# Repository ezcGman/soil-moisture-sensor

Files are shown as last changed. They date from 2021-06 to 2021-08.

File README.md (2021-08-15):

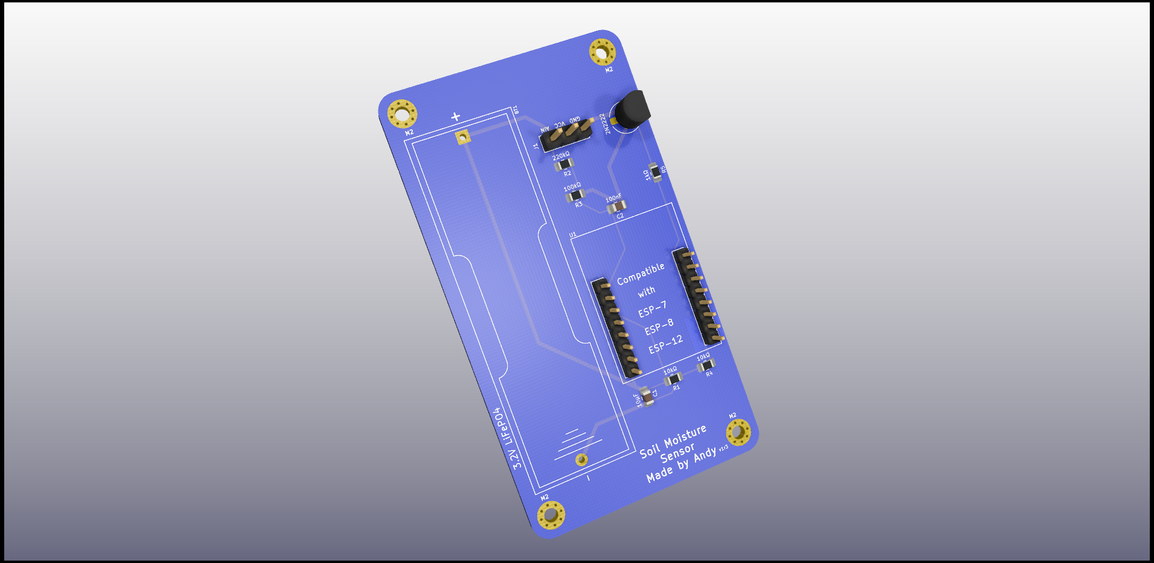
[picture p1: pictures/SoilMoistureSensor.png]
The PCB


# Soil Moisture Sensor
This is one of my first self designed PCBs in KiCad. It's a simple circuit which makes use of an ESP8266 and a soil moisture sensor to observe your plants. The cool thing: My custom socket supports the ESP-12E/F, the ESP-8 and the cool ESP-7, which comes with an external antennna!

## Credits
Shoutout to Quindor from QuinLED.info, the LED master himself. He tought me a lot about KiCad, PCB design and some more electrical engineering fundamentals! While I'm still miles away from being perfect, with his help I really feel confident in what I'm doing here!

## KiCad dependencies
It might happen that KiCad is missing my custom footprints. You can find and download them here and then add them to KiCad: https://github.com/ezcGman/andys-footprints

## Parts list
All these parts can be easily found on AliExpress (except the PCBs ;) ):

- 1x The PCB in this folder, printed e.g. at PCBWay
- 1x 3.2V LiFePO4 battery in AA form factor
- 1x AA battery holder for THT mounting
- 1x capactive soil moisture sensor (some notes on capacitive vs. resistive sensors can be found a bit further down)
- 1x bare ESP8266 module, so no devboard like the famous NodeMCU or D1 Mini. The socket supports the ESP-12E/F, ESP-8 and ESP-7. But in the end, there are only two choices:
  - ESP-12E/F: If you don't need an external antenna / your Wi-Fi signal is good, get this one. It's super common, easy to get and cheap.
  - ESP-7: If you do need an external antenna, get this one. Often also comes directly with an antenna! 
- 1x NPN transistor. Probably most transistors are fine, but I suggest the 2n2222(a) which is super common and totally sufficient for this
- 1x 0805 SMD capacitor of 10µF or bigger. But 0805 SMD caps are usually limited to ~40µF. So whatever u have around
- 1x 0805 SMD capacitor of 100nF
- 1x 0805 resistor of 1kΩ
- 2x 0805 resistor of 10kΩ
- 1x 0805 resistor of 100kΩ
- 1x 0805 resistor of 220kΩ
- 2x **2mm** (**not** 2.54mm!!) single row pin headers of 8 pins each
- 1x 2.54mm single row pin header of 3 pins

## Tools list
### Required
- A soldering iron
- Soldering tin

### Optional
- For SMD components:
  - A hot air soldering/reflow station. However, those are 0805 SMD components which can be done with a soldering iron
  - Solder paste
  - Tweezers

## The code
If you're familiar with ESP coding, this should all be straight forward, but some key things in there:
* The whole code is in setup() as the ESP goes through it when doing timed deep sleep using the GPIO16-to-RST method. Because the "wake up" is actually a reset, because the RST is pulled low.
* I'm using the sensor in Home Assistant through MQTT, so the code has some MQTT logic
* Both my Wi-Fi and MQTT connect routines have some reconnect logic.
* GPIO4 is used to switch on the sensor, so this is one of the very first things the code does. This is done by pulling it HIGH, which will switch the transistor which then makes the full circuit of the sensor complete, by letting the electrones flow from GND to the sensor.
* I then just read from the A0 pin, convert it in C-super-complicated-style (Python developer speaking here!) to a char and dropping it into an MQTT topic.
* It also has some percentage calculation, which is based on my own measurements of the sensor. These are the "air value" (so sensor just laying around) and the "water value" (which is the sensor put into a glas of clear water).
* Another thing is a "dry/wet threshold", which is based on my girlfriend: She said "Andy, this is now dry!". And I took this as the threshold (minus a little bit for earlier alerts) for considering a plant being dry. Note, that this may vary by plant and flower soil used.
* Ultimately not needed, but for easier checking if the battery is empty (=no signal is sent anymore): A "last updated" timestamp also dropped into the MQTT topic

### Dependencies
* Arduino Client for MQTT, >=v2.8.0: https://pubsubclient.knolleary.net/
* Optional (can use built-in DateTime): ESPDateTime, >=v1.0.4: https://github.com/mcxiaoke/ESPDateTime

## Schematic
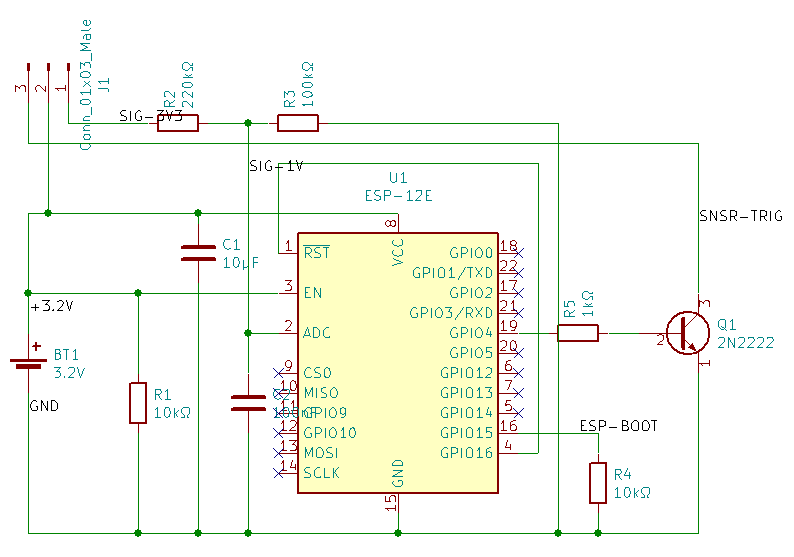
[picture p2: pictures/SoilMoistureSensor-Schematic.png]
The Schematic


## Why a bare ESP-12F, why not using a devboard like D1 or NodeMCU?
Easy answer: Power consumption + deep sleep. All these dev boards have an USB UART that is **always on**, even in deep sleep. And this eats a lot of energy. There is a really good post about why you should use ESP-12F over these devboards: https://github.com/z2amiller/sensorboard/blob/master/PowerSaving.md
Also: There is a reason why they are called **dev**boards ;) They are not really meant to be used "in production."

## Which kind of soil moisture sensors exist / should I use?
### 1. Electrical conduction sensors (Don't use: Boooo!)
When I was first playing with these soil moisture sensors, I've started with these sensors, which have a (visible) copper/some metal layer and two legs: They measure the soil moisture based on the electrical conduction of the soil / between the two legs.
The downside of these is that they can corrode and actually harm the plants, instead of surveiling them ;) And I don't know what upsides they actually have compared to:

### 2. Capacitive Soil Moisture Sensor (Use: Coooool!)
You guessed it: These sensors work by measuring the capacitance of the sensor (or it's layers (the electrodes)), where the soil and water function as the dielectric. These do not have copper layers being exposed which could corrode, so make them safe to use in any plant.
If you **really** want to deep dive into how these sensors work and how to properly calibrate them, lead this publication: https://www.researchgate.net/publication/342751186_Capacitive_Soil_Moisture_Sensor_Theory_Calibration_and_Testing

## How it looks
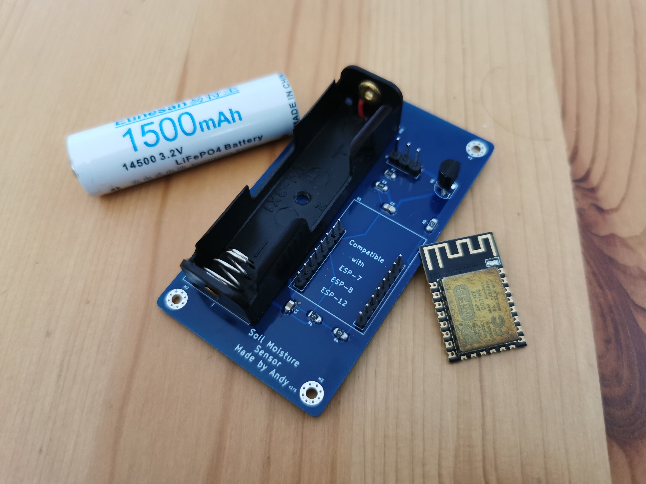
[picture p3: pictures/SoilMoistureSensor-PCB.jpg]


## Example application with an ESP-07 / external antenna outside (waterproof)
*Yes, I know: This is currently an ESP-12F, because I'm waiting for the ESP-07 to arrive. But then this will be powered by an ESP-07 ;)*
I just used an old jelly glass, drilled two holes in it and sealed them with hot glue. Therefore it's perfectly waterproof :)
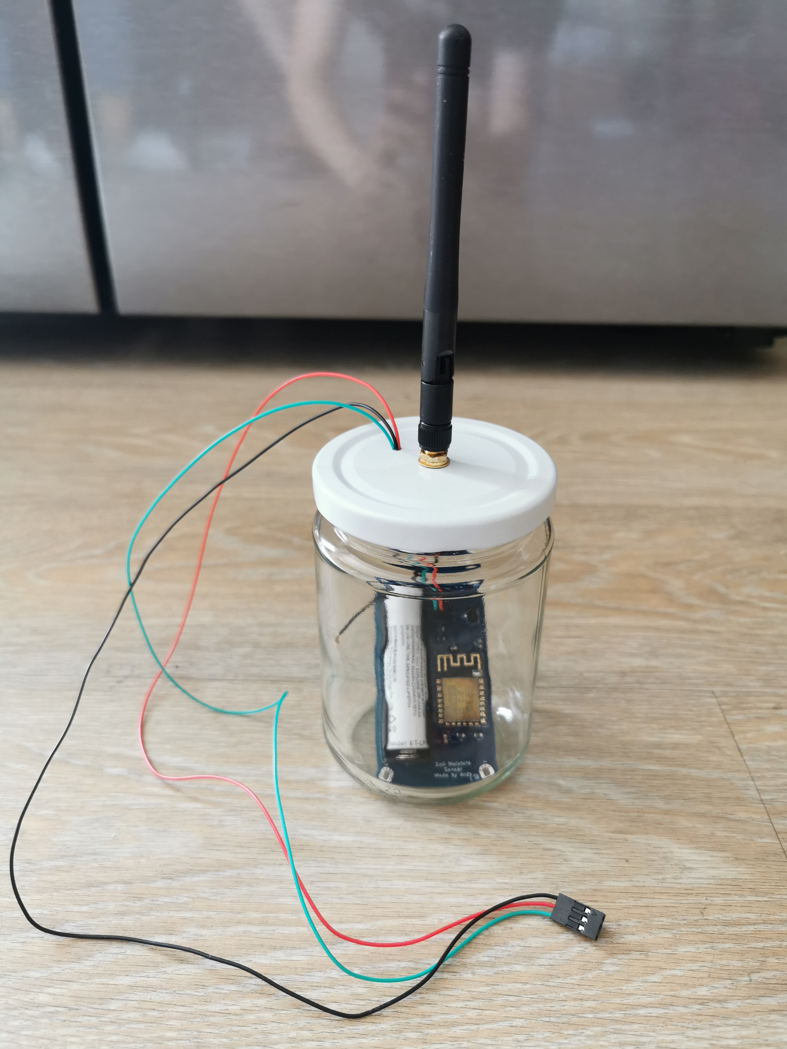
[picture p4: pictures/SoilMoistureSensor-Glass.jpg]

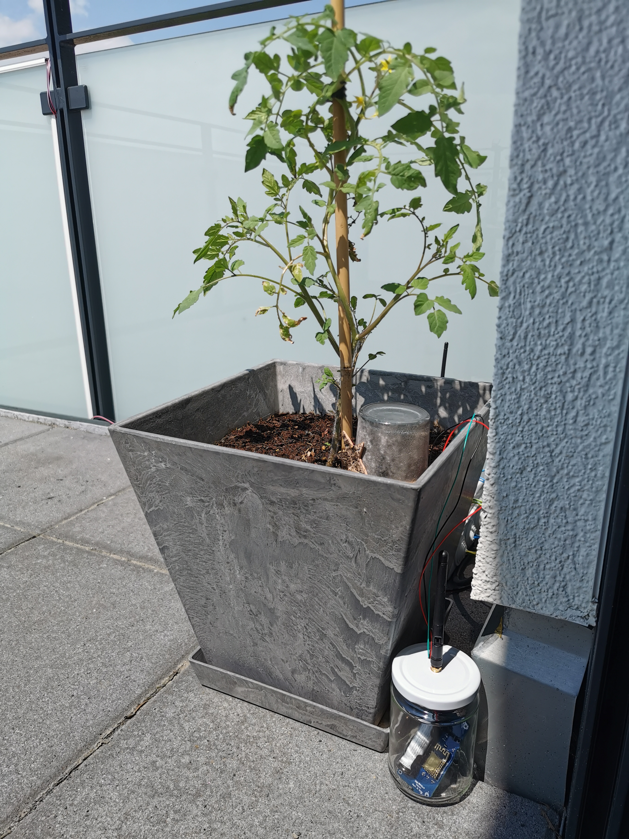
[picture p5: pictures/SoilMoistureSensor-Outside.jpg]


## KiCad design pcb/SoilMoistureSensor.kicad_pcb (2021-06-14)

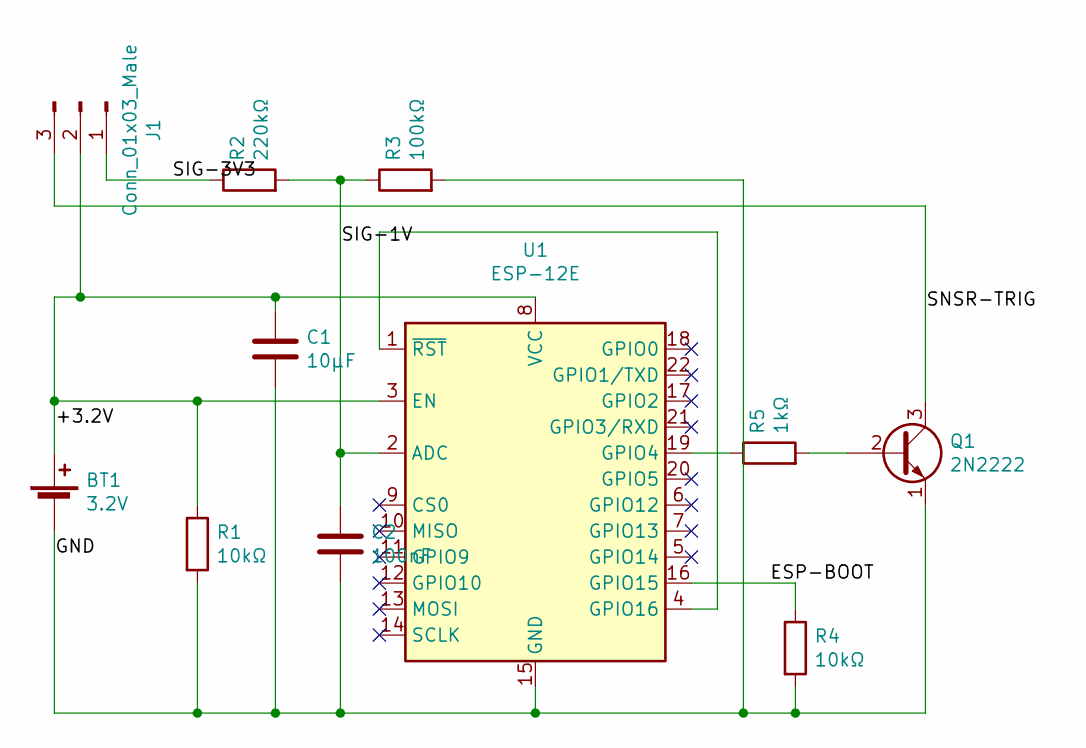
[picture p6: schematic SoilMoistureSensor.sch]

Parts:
BT1: 3.2V; BatteryHolder_Keystone_2460_1xAA-removed-holes
C1: 10µF; C_0805_2012Metric_Pad1.18x1.45mm_HandSolder
C2: 100nF; C_0805_2012Metric_Pad1.18x1.45mm_HandSolder
J1: Conn_01x03_Male; PinHeader_1x03_P2.54mm_Vertical-Fixed-SilkScreen
Q1: 2N2222; TO-92_HandSolder
R1, R4: 10kΩ; R_0805_2012Metric_Pad1.20x1.40mm_HandSolder
R2: 220kΩ; R_0805_2012Metric_Pad1.20x1.40mm_HandSolder
R3: 100kΩ; R_0805_2012Metric_Pad1.20x1.40mm_HandSolder
R5: 1kΩ; R_0805_2012Metric_Pad1.20x1.40mm_HandSolder
U1: ESP-12E; ESP-12-Socket

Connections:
/+3.2V: BT1.1 (+), C1.1, J1.2, R1.1, U1.3 (EN), U1.8 (VCC)
/ESP-BOOT: R4.1, U1.16 (GPIO15)
/GND: BT1.2 (-), C1.2, C2.2, Q1.1 (E), R1.2, R3.2, R4.2, U1.15 (GND)
/SIG-1V: C2.1, R2.2, R3.1, U1.2 (ADC)
/SIG-3V3: J1.1, R2.1
/SNSR-TRIG: J1.3, Q1.3 (C)
unnamed: Q1.2 (B), R5.2
unnamed: R5.1, U1.19 (GPIO4)
unnamed: U1.1 (~RST), U1.4 (GPIO16)

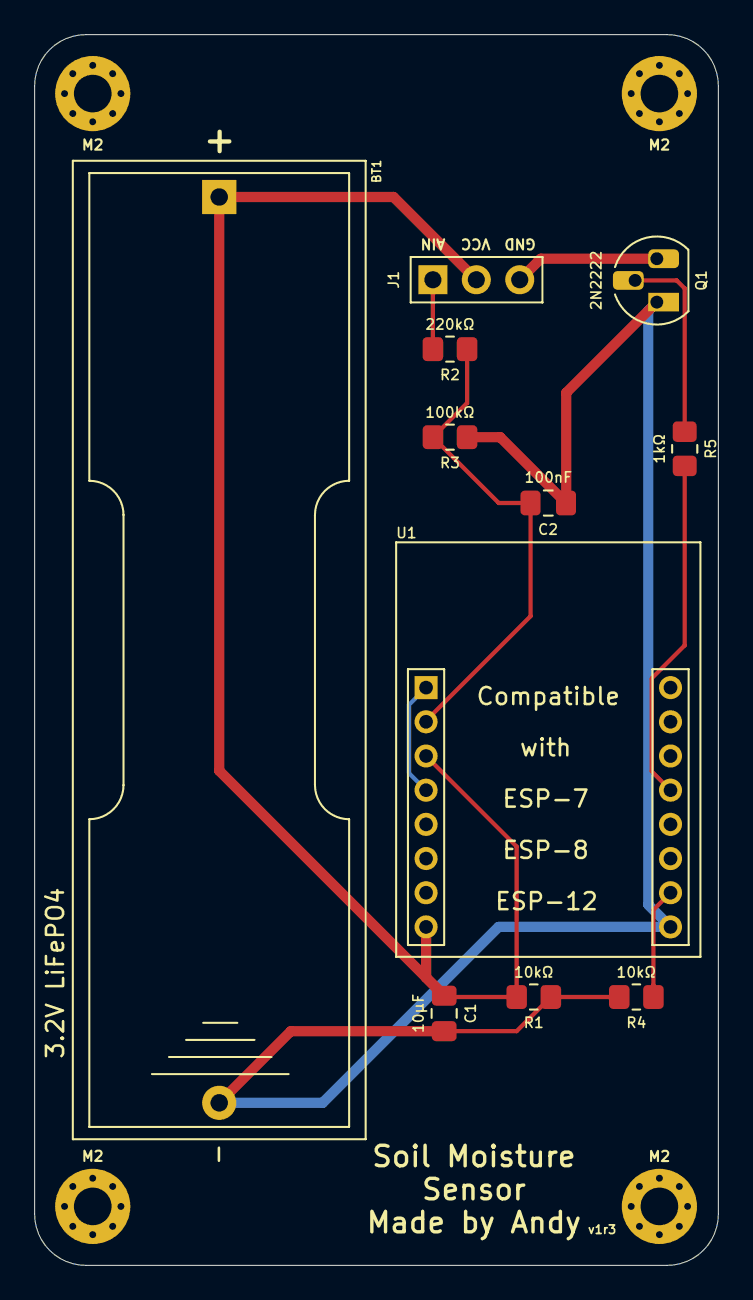
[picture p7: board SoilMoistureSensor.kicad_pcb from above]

Board: 2 copper layers, 40.0 x 72.0 mm, 15 parts (0 on the bottom side), 9 nets.

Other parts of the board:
M2, M2#2, M2#3, M2#4: MountingHole_2.2mm_M2_Pad_Via

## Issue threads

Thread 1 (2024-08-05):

How long does the battery last?

roycepope, 2024-08-05:

ezcGman, 2024-08-06:
Long ago I used them (nothing wrong with them, just the plant doesn't exist anymore), so I'm not totally sure, but I think it was around 3 weeks. You can increase it if you increase the deep sleep time in code

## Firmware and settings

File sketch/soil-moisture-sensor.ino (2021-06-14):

#include <ESP8266WiFi.h>
// Using https://pubsubclient.knolleary.net/
#include <PubSubClient.h>
// Using https://github.com/mcxiaoke/ESPDateTime
#include <DateTime.h>


const char* wifiSsid     = "YourSSID";
const char* wifiPassword = "YourWiFiPassword";

const char* mqttServer = "YourMQTTServer";
const int mqttPort = 1883;
const char* mqttUser = "YourMQTTUser";
const char* mqttPassword = "YourMQTTPassword";

// Used for Wi-Fi and MQTT
const byte maxConnTries = 15;

// https://github.com/esp8266/Arduino/blob/master/variants/nodemcu/pins_arduino.h
const byte analogMoisturePin = A0;
const byte enableSensorPin = 4;

// Measured myself, using this guide: https://media.digikey.com/pdf/Data%20Sheets/DFRobot%20PDFs/SEN0193_Web.pdf
const int airValue = 910;
const int waterValue = 412;
// The original script devides into "Very wet", "Wet" and "Dry". But we will only care about "Dry", but we keep the sectioning
// int intervals = (airValue - waterValue) / 3;
// I on the other hand thought that maybe 60% on the way to the air value may be considered "dry":
// const int plantDryThreshold = ((airValue - waterValue) * 0.6) + waterValue;
// But my girlfriend said "This now is dry!". And "this" was around the 570 mark. And girls are always right ¯\_(ツ)_/¯
// Even if I think that we should set the threshold to 570 then, I still go ahead and set it to 550, to have the alert trigger a bit earlier.
// Yes, that should be in the alerting systems business logic, but we use this boolean flag in the alerting. So we set this flag a little earlier.
const int plantDryThreshold = 550;

WiFiClient wifiClient;
/*
 * To speed up Wi-Fi conenction, you can hardcode these values and use the
 * alternate WiFi.config() and WiFi.begin() calls in connectWifi()
const byte wifiChannel = 7;
IPAddress ipEsp(192, 168, 178, 100);
IPAddress ipRouter(192, 168, 178, 1);
IPAddress subnet(255, 255, 255, 0);
uint8_t macRouter[6] = { 0xAA, 0xBB, 0xCC, 0xDD, 0xEE, 0xFF };
*/
PubSubClient mqttClient(wifiClient);


void connectWifi() {
  if (WiFi.status() != WL_CONNECTED) {
    int wifiConnTries = 0;

    WiFi.mode(WIFI_STA);
/*
 * Use these two calls for faster Wi-Fi connection.
    WiFi.config(ipEsp, ipRouter, ipRouter, subnet);
    WiFi.begin(wifiSsid, wifiPassword, wifiChannel, macRouter);
*/
    WiFi.begin(wifiSsid, wifiPassword);
    while (WiFi.status() != WL_CONNECTED && wifiConnTries < maxConnTries) {
      wifiConnTries++;
      Serial.printf("Connecting to Wi-Fi %s ...\n", wifiSsid);
      delay(1000);
    }

    if (WiFi.status() != WL_CONNECTED && wifiConnTries >= maxConnTries) {
      Serial.println("Maximum number of Wi-Fi connection attempts reached. Rebooting...");
      ESP.restart();
    }

    Serial.printf("Connected to Wi-Fi! IP address: %s\n", WiFi.localIP().toString().c_str());
  }
}

void connectMqtt() {
  if (!mqttClient.connected()) {
    int mqttConnTries = 0;
    while (!mqttClient.connected() && mqttConnTries < maxConnTries) {
      mqttConnTries++;
      Serial.printf("Connecting to MQTT server at %s on port %d ...\n", mqttServer, mqttPort);

      if (!mqttClient.connect("esp8266-doorbell", mqttUser, mqttPassword )) {
        Serial.print("Failed with state ");
        Serial.println(mqttClient.state());
        delay(1000);
      }
    }

    if (!mqttClient.connected() && mqttConnTries >= maxConnTries) {
      Serial.println("Maximum number of MQTT connection attempts reached. Rebooting...");
      ESP.restart();
    }

    Serial.println("Connected to MQTT server!");
  }
}

// Sometimes values can go over or under our thresholds, so we just cap them on both ends to have meaningful percentage values
float sanitizeSoilMoistureValue(float soilMoistureValue) {
  if (soilMoistureValue < waterValue && soilMoistureValue > 0) {
    soilMoistureValue = waterValue;
  }
  else if (soilMoistureValue > airValue) {
    soilMoistureValue = airValue;
  }

  return soilMoistureValue;
}

void setup() {
  pinMode(LED_BUILTIN, OUTPUT);
  pinMode(enableSensorPin, OUTPUT);

  digitalWrite(LED_BUILTIN, LOW);
  digitalWrite(enableSensorPin, HIGH);

  Serial.begin(9600);

  // The Wi-FI library has auto-reocnnect. So we simply call it in setup() and there is no need to always check the conenction in loop()
  connectWifi();

  mqttClient.setServer(mqttServer, mqttPort);
  connectMqtt();

  float soilMoistureValue = analogRead(analogMoisturePin);
  Serial.printf("Raw value: %f\n", soilMoistureValue);

  soilMoistureValue = sanitizeSoilMoistureValue(soilMoistureValue);
  Serial.printf("Sanitized value: %f\n", soilMoistureValue);

  char charMoistureValue[4];
  int intMoistureValue = soilMoistureValue;
  sprintf(charMoistureValue, "%d", intMoistureValue);
  mqttClient.publish("home-assistant/plant-sensors/balcony/tomato/moisture", charMoistureValue, true);

  float wetPercentage = 100 - ((soilMoistureValue - waterValue) / (airValue - waterValue) * 100);

  Serial.printf("Wet Percentage: %.2f\%\n", wetPercentage);
  char charWetPercentage[7];
  sprintf(charWetPercentage, "%.2f", wetPercentage);
  mqttClient.publish("home-assistant/plant-sensors/balcony/tomato/wet-percentage", charWetPercentage, true);

  int isWet = 1;
  if(soilMoistureValue > plantDryThreshold) {
    isWet = 0;
  }
  Serial.printf("Is wet: %d\n", isWet);

  char charIsWet[1];
  sprintf(charIsWet, "%d", isWet);
  mqttClient.publish("home-assistant/plant-sensors/balcony/tomato/wet", charIsWet, true);

  DateTime.begin();
  int dateTimeTries = 0;
  while (!DateTime.isTimeValid() && dateTimeTries < 3) {
      dateTimeTries++;
      Serial.println("Failed to get time from server.");
  }
  String strDateTime = DateTime.format("%Y-%m-%dT%H:%M:%S%z");
  char charDateTime[strDateTime.length()];
  strDateTime.toCharArray(charDateTime, strDateTime.length());
  mqttClient.publish("home-assistant/plant-sensors/balcony/tomato/lastUpdated", charDateTime, true);

  digitalWrite(enableSensorPin, LOW);
  digitalWrite(LED_BUILTIN, HIGH);

  delay(100);
  ESP.deepSleep(15*60e6); // Deep Sleep for 15 minutes
}

void loop() {
}

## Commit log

2021-06-08 Added schematic
2021-06-10 Fixed turning off LED
    [soil-moisture-sensor.ino]
2021-06-14 PCB v1r3: Made it 40mm width again, as it fits perfectly in old tomato sauce glasses ;)
    [SoilMoistureSensor.kicad_pcb]
